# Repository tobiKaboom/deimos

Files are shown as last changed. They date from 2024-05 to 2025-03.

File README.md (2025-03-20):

# Δεῖμος
Deimos is a 40% split unibody ortholinear keyboard that uses the Raspberry Pi Pico for more accessibility, whose layout is similiar to the Lesovoz but has easier kitting. 

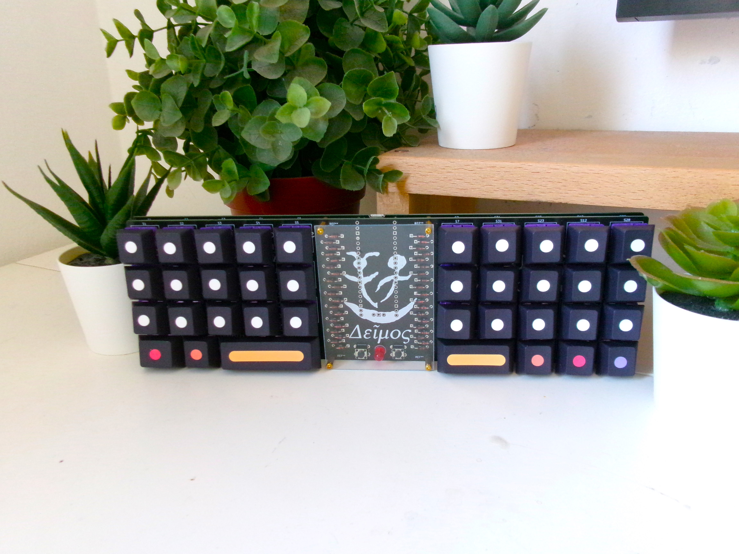
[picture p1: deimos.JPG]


keyboard-layout

## Parts list
| Part | Specifics | Amount |
| --- | --- | --- |
| Diodes | DO-35 THT diodes (part number 1N4148)  | 38 |
| Switches | MX standard switches  | 37 |
| Board | Raspberry Pi Pico (classic board) | 1 |
| Buttons | 6mm micro-switches | 2 |
| LED | 5mm LED | 2 |
| Electrical tape | - | 1 |
| Resistor | 220 ohm | 1 |
## Tools list
| Tools | Is it necessary? | Use |
| --- | --- | --- |
| Soldering iron | Yes  | Soldering |
| Solder wire| Yes | Soldering |
| Screwdriver | Yes | Screwing in standoffs |
| Tape | No, but reccomended | Holding components in place |
| Tweezers | No, but reccomended | Placing smaller parts |
| Fan or solder hood | No, but reccomended | Safety |
| Eye protection | No, but reccomended | Safety |

## Firmware 
Deimos currently runs on KMK. If you want to try and port it to QMK, ZMK or any other firmware you are welcome to do so.

## License
This work falls under the Creative Commons Attribution-ShareAlike 4.0 international license.
For more info, check LICENSE.md or https://creativecommons.org/licenses/by-sa/4.0/deed.en

## Issues
The right button is supposed to light up the LED, but it will burn it out. I am dumb. Use a resistor to avoid that.

## Disclaimer
This PCB has been fully tested and confirmed to work. The members of the PCB development team are however not liable if you end up with a non-functional pcb. Order at your own risk. Support will not be provided but pull requests will be reviewed and possibly accepted, although i do not know how that works.

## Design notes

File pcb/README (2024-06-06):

deimosproduction.zip is the file with all the gerbers, if you are using JLCPCB or PCBway you can just drag and drop it in there.
if you want to edit the raw file, which i advise not to do as it's very confusing even for me, the designer, you have to download and add to your KiCAD libraries Joe Scotto's 
libraries specifically for keyboards.

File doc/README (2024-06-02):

deimos.stl is simply the stl version of deimos.step

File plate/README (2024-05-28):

all these plates are 1.4mm thick, deimosplate.stl contains both the plates while deimosrighthalf.stl and deimoslefthalf.stl are self-descriptive.

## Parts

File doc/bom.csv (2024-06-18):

Designator | Footprint | Quantity | Value | LCSC Part #
D1_2, D1, D10_2, D10, D11_4, D11_3, D11_2, D11, D12_2, D12, D13_2, D13, D14_2, D14, D15_2, D15, D16_2, D16, D17_2, D17, D18_2, D18, D2_2, D2, D3_2, D3, D4_2, D4, D5_2, D5, D6_2, D6, D7_2, D7, D8_2, D8, D9_2, D9 | DO-35 | 38 | Diode
S1, S10, S11, S12, S13, S14, S16, S17, S18, S19, S2, S20, S21, S22, S23, S24, S26, S27, S28, S29, S3, S30, S31, S32, S33, S34, S35, S36, S37, S4, S5, S6, S7, S9 | MX_PCB_1.00u | 34 | Keyswitch
S15 | MX_PCB_2.75u | 1 | Keyswitch
S25 | MX_PCB_2.00u | 1 | Keyswitch
S8 | MX_PCB_1.25u | 1 | Keyswitch
U1 | Raspberry_Pi_Pico | 1 | Raspberry_Pi_Pico

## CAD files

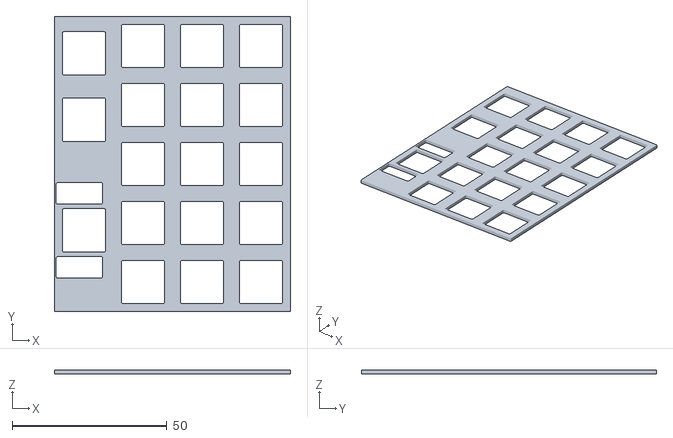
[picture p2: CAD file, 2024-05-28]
plate/deimoslefthalf.stl
76.2 x 95.2 x 1.40

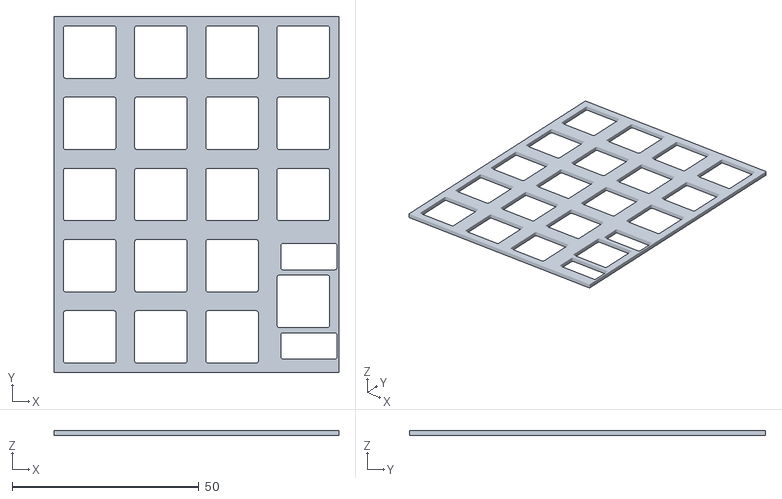
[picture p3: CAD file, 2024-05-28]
plate/deimosrighthalf.stl
76.2 x 95.2 x 1.40

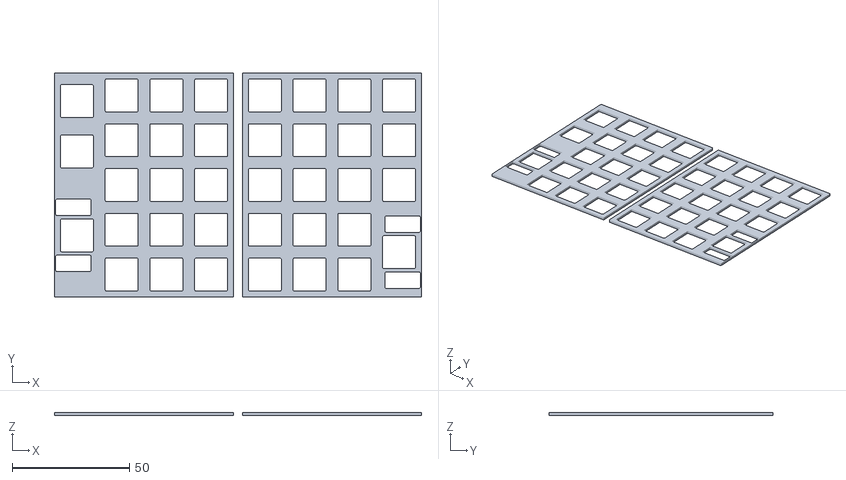
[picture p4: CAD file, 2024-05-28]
plate/deinosplate.stl
156.2 x 95.2 x 1.40

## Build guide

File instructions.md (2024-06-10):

*ignore the shakey pictures. i cannot hold my hand still.
## 1 - Standoffs
Screw your standoffs to the board. I reccomend 5mm under the keeb and 10mm where the parts are supposed to be shown
## 2 - Diodes 
IMG-20240606-WA0033
Solder in the diodes. Make sure the black line is facing towards the square pad.
## 3 - Buttons and LED
IMG-20240606-WA0039
Solder the buttons and the LED, making sure the flat side of the LED matches up with the flat side of the LED footprint on the board. If you want your LED to be on while your board is on, solder a 220 ohm resistor between two pins on opposite sides of the right button, as in one leg on the right and one leg on the left side. If you don't want it to be always on, just dont press the button. Otherwise it might burn out.
## 4 - Switches
IMG-20240609-WA0013
Solder in the switches.
## 5 - Raspberry Pi
IMG-20240609-WA0015
Put some electrical tape where the Pi is supposed to touch the board. There should be no electrical contacts but do that just to be sure. Hold the pi still and solder it directly to the board, if you want putting through the holes some diode legs.
## 6 - Keycaps and plastic cover
Put the keycaps on your switches. Get a thin piece of acrylic and cut it to the right size, make the holes to put the screws through and screw it to the standoffs over the components in the middle.

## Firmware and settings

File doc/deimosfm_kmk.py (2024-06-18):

#reading this code will kill half your neurons. proceed with caution.
print("its a me mario")

import board

from kmk.kmk_keyboard import KMKKeyboard
from kmk.keys import KC
from kmk.scanners import DiodeOrientation
from kmk.modules.layers import Layers

keyboard = KMKKeyboard()

keyboard.col_pins = (board.GP0, board.GP1, board.GP2, board.GP3, board.GP5, board.GP4, board.GP6, board.GP7, board.GP8, board.GP9) #gp4 and gp5 are swapped, but that's correct!
keyboard.row_pins = (board.GP19, board.GP18, board.GP17, board.GP16)
keyboard.diode_orientation = DiodeOrientation.COL2ROW

#very cooler names
___ = KC.TRNS
XXX = KC.NO

keyboard.keymap = [
                  [#base
                   KC.Q, KC.W, KC.E, KC.T, KC.Y,                 KC.R, KC.U, KC.I, KC.O, KC.P, #some keys are flipped but they need to be like that dont ask me why i didnt design this board (i did but i have no idea why it does that)
                   KC.A, KC.S, KC.D, KC.G, KC.H,                 KC.F, KC.J, KC.K, KC.L, KC.ENT,
                   KC.Z, KC.X, KC.C, KC.B, KC.B,                 KC.V, KC.N, KC.M, KC.COMM, KC.DOT,
                   KC.LCTRL, KC.LWIN, XXX, XXX, KC.MO(3),        KC.SPC, XXX, KC.RALT, KC.MO(1), KC.MO(2)
                   ]
                  [#layer 1
                   KC.N1, KC.N2, KC.N3, KC.N5, KC.N6,            KC.N4, KC.N7, KC.N8, KC.N9, KC.N0,
                   KC.GRV, KC.NUBS, XXX, XXX, XXX,               KC.DEL, XXX, XXX, KC.MINUS, KC.EQUAL,
                   KC.LSHIFT, KC.F2, KC.F3, KC.F5, KC.F6,        KC.F4, KC.F7, KC.F8, KC.F9, KC.F10,
                   KC.LCTRL, KC.F1, XXX, XXX, XXX,               KC.F11, KC.F12, XXX, XXX, XXX
                   ]
                  [#yummy layer 2
                   KC.ESC, KC.UP, XXX, XXX, XXX,                 XXX, KC.PSCR, KC.SLCK, KC.PAUSE, KC.BSPC,
                   KC.LEFT, KC.DOWN, KC.RIGHT, KC.HOME, KC.NO,   KC.END, KC.INS, KC.HOME, KC.PGUP, XXX,
                   KC.LSHIFT, KC.F14, KC.F15, KC.F17, KC.NO,    KC.F16, KC.DEL, KC.END, KC.PGDOWN, XXX,
                   KC.LCTRL, KC.F19, XXX, KC.NO, XXX,           KC.F20, XXX, XXX, XXX, XXX
                   ]
                  [#i dont want to code anymore but layer 3
                   XXX, XXX, XXX, XXX, XXX,                      XXX, XXX, KC.LBRC, KC.RBRC, KC.BSLS,
                   XXX, XXX, XXX, XXX, XXX,                      XXX, XXX, XXX, KC.SCLN, KC.QUOTE,
                   KC.LSHIFT, XXX, XXX, XXX, XXX,                XXX, XXX, XXX, XXX, KC.SLSH,
                   KC.LCTRL, LGUI, XXX, XXX, XXX,                XXX, XXX, XXX, KC.RGUI, KC.RCTL
                   ]
]

    keyboard.go()

#this is simply the layout i like to use. to edit it, download it and to change the keymap refer to kmkfw.io and the multiple tutorials available on youtube.
